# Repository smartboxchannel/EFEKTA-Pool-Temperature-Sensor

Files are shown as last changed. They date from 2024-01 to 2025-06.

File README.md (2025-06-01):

# EFEKTA-Pool-Temperature-Sensor

Проект zigbee датчика температуры для бассейна. Проект разработан на soc сс2530 (радиомодуль E18-MS1PA2-IPX, E18-MS1PA2-PCB, E18-MS1-PCB)

Телеграм чат DIY Devices - https://t.me/diy_devices

Продажа DIY Устройств - https://t.me/diydevmart

Видео инструкция, Ютуб канал SGHome - https://youtu.be/Cri-8IdNB2Q

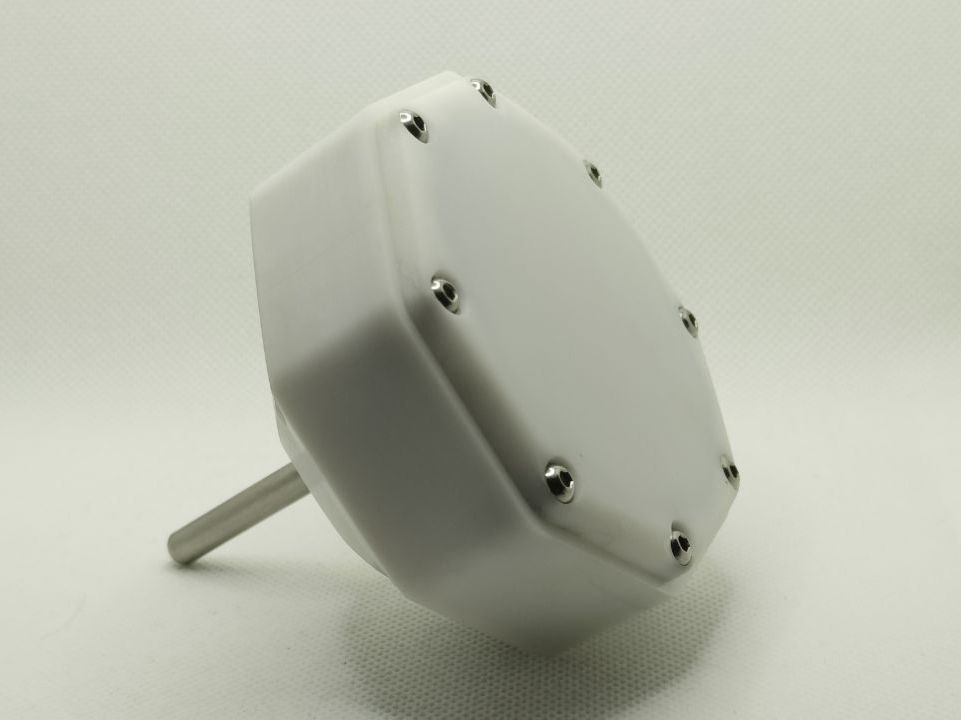
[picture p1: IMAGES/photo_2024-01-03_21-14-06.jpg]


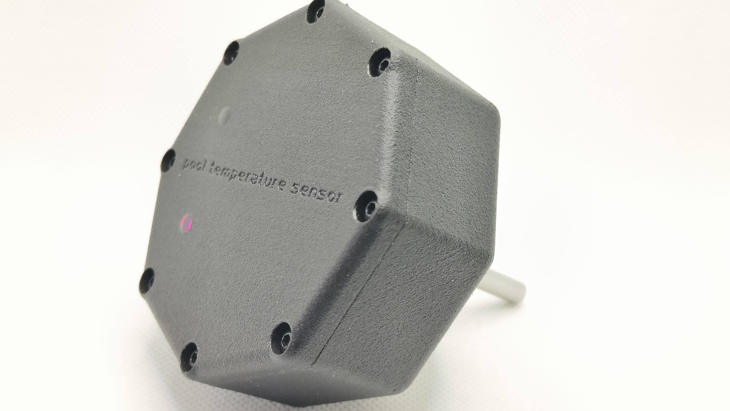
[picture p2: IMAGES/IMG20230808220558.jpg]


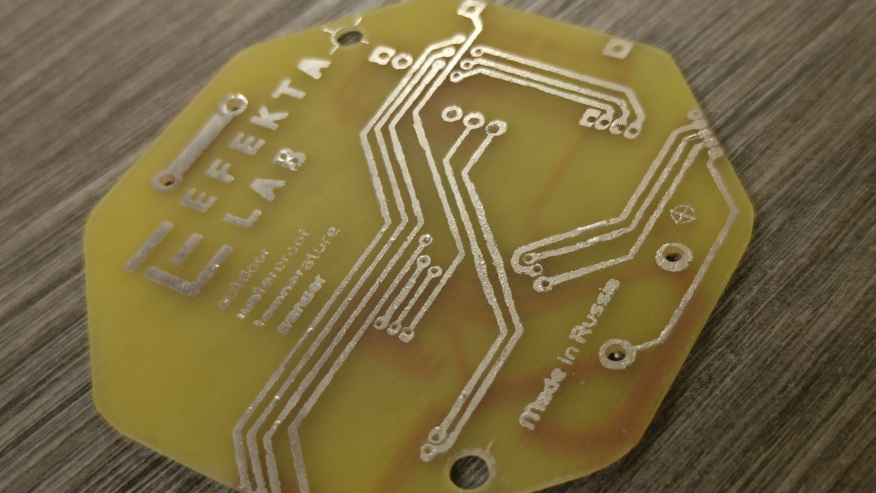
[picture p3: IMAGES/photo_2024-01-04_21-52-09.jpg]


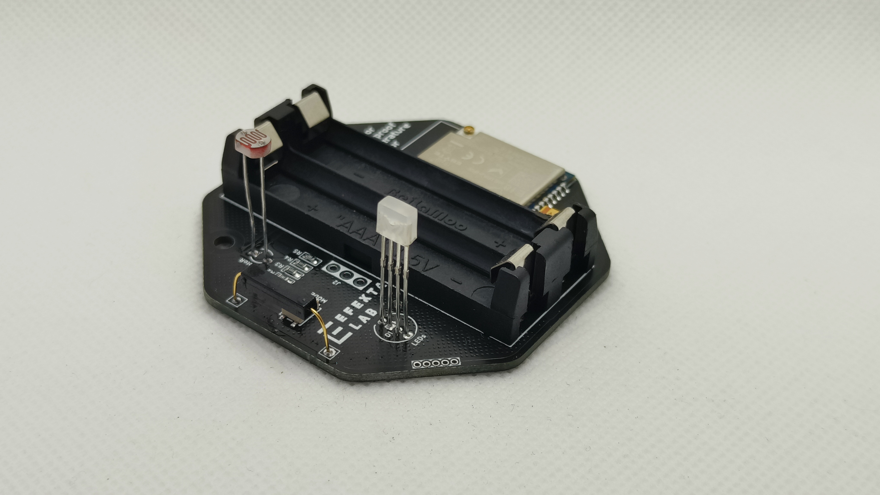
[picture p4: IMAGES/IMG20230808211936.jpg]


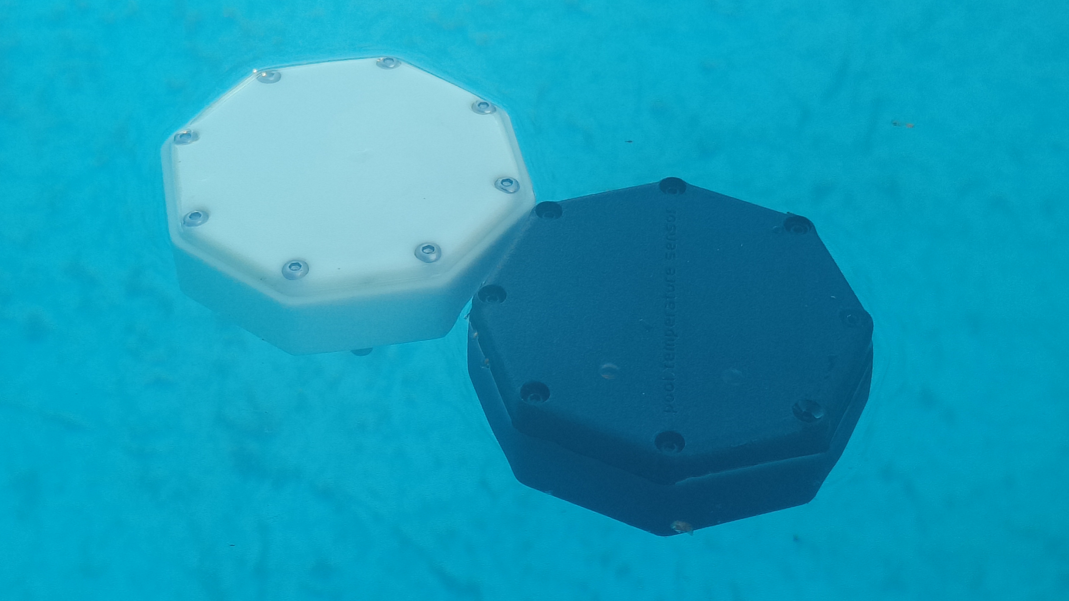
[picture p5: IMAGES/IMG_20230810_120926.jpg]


## Установка среды разработки IAR

https://github.com/sigma7i/zigbee-wiki/wiki/zigbee-firmware-install

https://zigdevwiki.github.io/Begin/IAR_install/

### Программа для разработки печатных плат - DipTrace

https://diptrace.com/rus/download/download-diptrace/

### Корпус спроектирован в SOLIDWORKS

### Прошивка устройства

Вам понадобится программа SmartRF Flash Programmer версии 1. Так же вам понадобится CC Debugger или Smart RF04E(рекомендуется из-за простоты подключения).

#### Процесс прошивки с помощью SmartRF Flash Programmer v1

Подключите 5 контактов на плате на соответствующие подписанные контакты дебагера. Подключаете дебагер в usb порту компьютера, открываете программу SmartRF Flash Programmer v1. Правее поля в пункте Flash Image нажимаете на иконку «обзор» и выбираете файл прошивки скачанный ранее. В пункте Actions выбираете Erase и ниже нажимаете на кнопку Perform actions. После того как вы очистили чип, выбираете Erase and program том же в пункте Actions и снова нажимаете кнопку Perform actions.

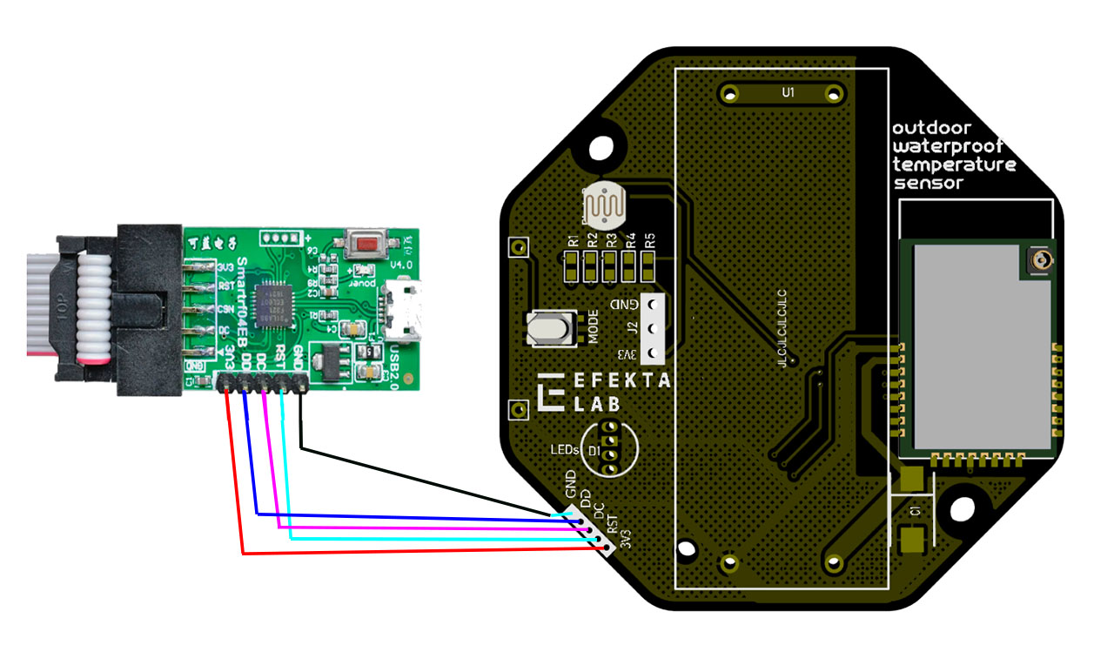
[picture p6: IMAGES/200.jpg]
Flash Programm EFEKTA Pool Temperature Sensor


### Установка внешнего конвертера Z2M

Для добавления внешнего конвертера необходимо выполнить «2 шага». Первый — загрузить сам файл конвертера на ваш сервер, а второй — внести информацию в файл конфигурации о внешнем конвертере в zigbee2mqtt.

To add an external converter you need to perform "2 steps". The first is to upload the converter file itself to your server and the second is to enter information into the configuration about the external converter in zigbee2mqtt. 

#### Добавление файла на сервер.

/UPD
##### Вариант 0.
Если вы используете Home Assistant то загрузить файлы на сервер можно воспользовавшись аддоном File editor (самый простой вариант).

##### 0 option.
If you use Home Assistant to upload files to the server, you can use the File Editor addon (the easiest option).
/

##### Вариант 1.

Для загрузки конвертера для устройсва на сервер УД есть несколько вариантов. Первое это загрузка через ftp клиент. Это может быть любой клиент, например filezilla.

Для подключения к серверу необходимо ввести ip адрес, логин и пароль в соответствуюшие поля в программе и нажать на кнопку - "быстрое подключение"

There are several options for uploading a device converter to the server. The first is uploading via an ftp client. This can be any client, for example filezilla.

To connect to the server, you must enter the IP address, login and password in the appropriate fields of the program and click the “quick connection” button.

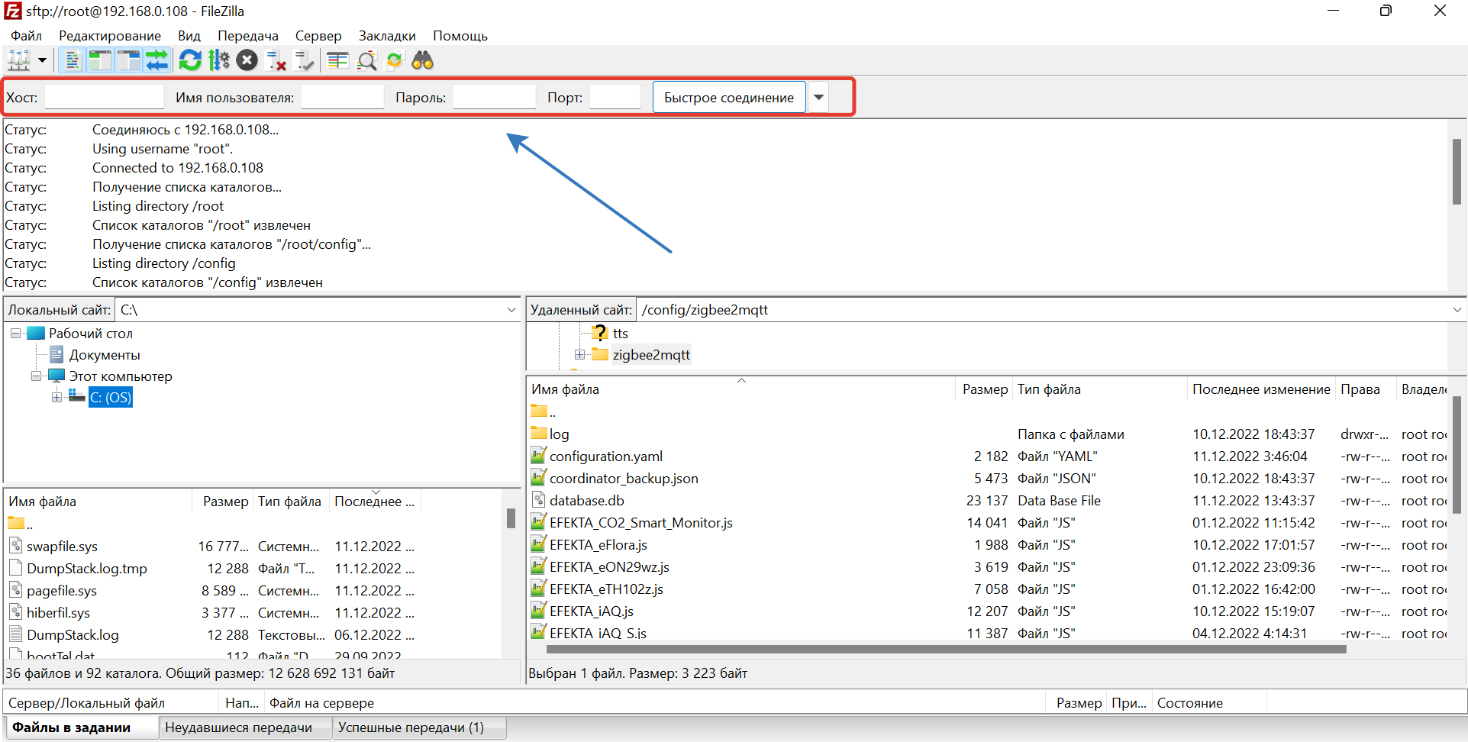
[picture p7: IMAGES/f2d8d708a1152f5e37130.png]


Если вы не используете HassOs то путь к нужной папке будет /opt/zigbee2mqtt/data, если вы используете HassOs то путь к нужной папке будет /config/zigbee2mqtt

Перейдя в нужную папку просто перетащите туда конвертер из левого окна программы в правое.

If you are not using HassOs, then the path to the desired folder will be /opt/zigbee2mqtt/data, if you are using HassOs, then the path to the desired folder will be /config/zigbee2mqtt

Having gone to the desired folder, simply drag the converter there from the left program window to the right one.

##### option 2

Если вы используете Home Assistant то вы можете установить плагин Самба, тогда у вас появится сетевая папка в которую вы можете просто перетащить нужный файл через стандартный проводник в Windows. Инструкция по установке Самба находится здесь http://psenyukov.ru/%D0%B4%D0%B5%D0%BB%D0%B0%D0%B5%D0%BC-%D1%81%D0%B5%D1%82%D0%B5%D0%B2%D1%8B%D0%B5-%D0%BF%D0%B0%D0%BF%D0%BA%D0%B8-%D0%BD%D0%B0-%D1%81%D0%B5%D1%80%D0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.

If you use Home Assistant, then you can install the Samba plugin, then you will have a network folder created in you can simply move the desired file through the standard Windows Explorer. Instructions for installing Samba are here http://psenyukov.ru/%D0%B4%D0%B5%D0%BB%D0%B0%D0%B5%D0%BC-%D1%81%D0%B5%D1%82%D0%B5%D0%B2%D1%8B%D0%B5-%D0%BF%D0%B0%D0%BF%D0%BA%D0%B8-%D0%BD%D0%B0-%D1%81%D0%B5%D1%80%D0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.

#### Добавление записи о внешнем конвертере.

После загрузки файла (это самая трудная часть обычно :)), нужно прописать данные о внешнем конвертере в конфигурацию zigbee2mqtt. Для этого вам нужно перейти в вэбинтерфейс zigbee2mqtt и перейти в раздел - 'настройки".

далее найти подраздел - внешние конвертеры и перейти в него.

After downloading the file (this is usually the hardest part :)), you need to register the data in the external converter in the zigbee2mqtt configuration. To do this, you need to go to the zigbee2mqtt interface and go to the “Settings” section.

Next, find the section - External converters and go to it.

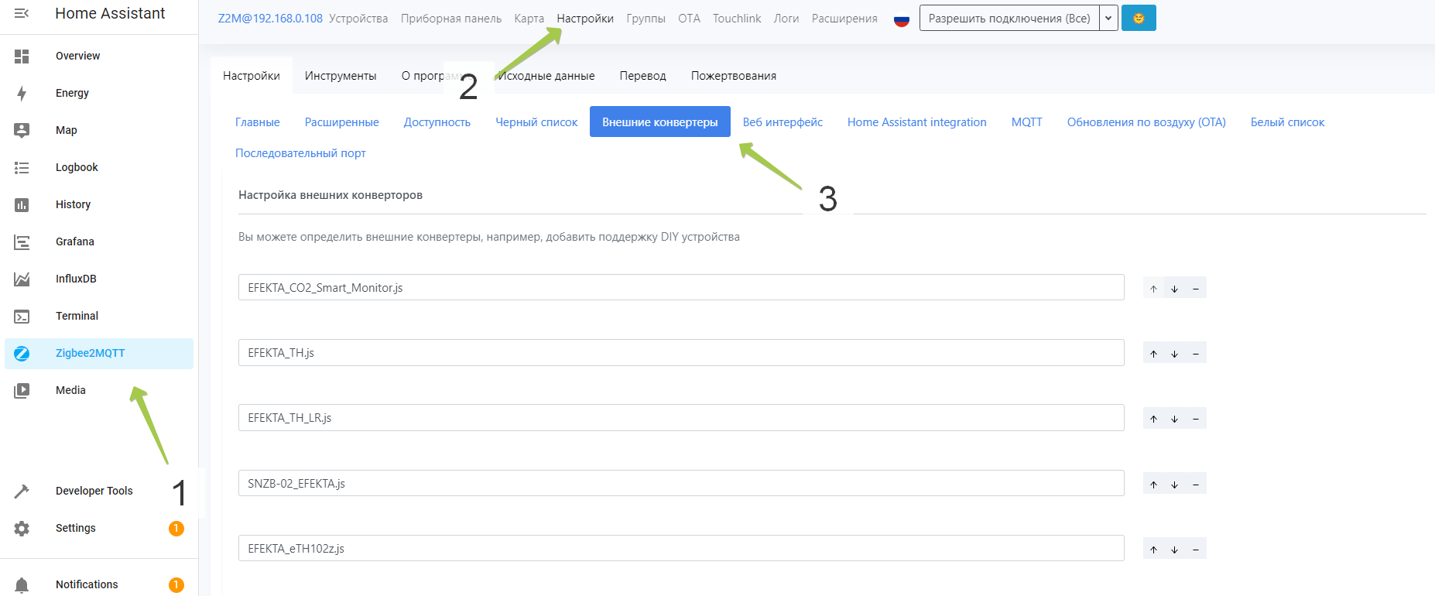
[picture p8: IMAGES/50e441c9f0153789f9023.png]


Далеее нужно спустится вниз страницы и нажать на кнопку "+", появися новое окно для ввода информации, туда нужно добавить название вашего внешнего конвертера с расширением. например Pool_Temperature_smart_sensor.js. После этого нажать на кнопку 'Submit" и далее на кнопку - "Перезагрузить" вверху страницы.

Next, you need to scroll down the page and click the “+” button, a new window will appear for entering information, where you need to add the name of your external converter with extensions. for example Pool_Temperature_smart_sensor.js. After that, click on the “Submit” button and then on the “Reload” button at the top of the page.

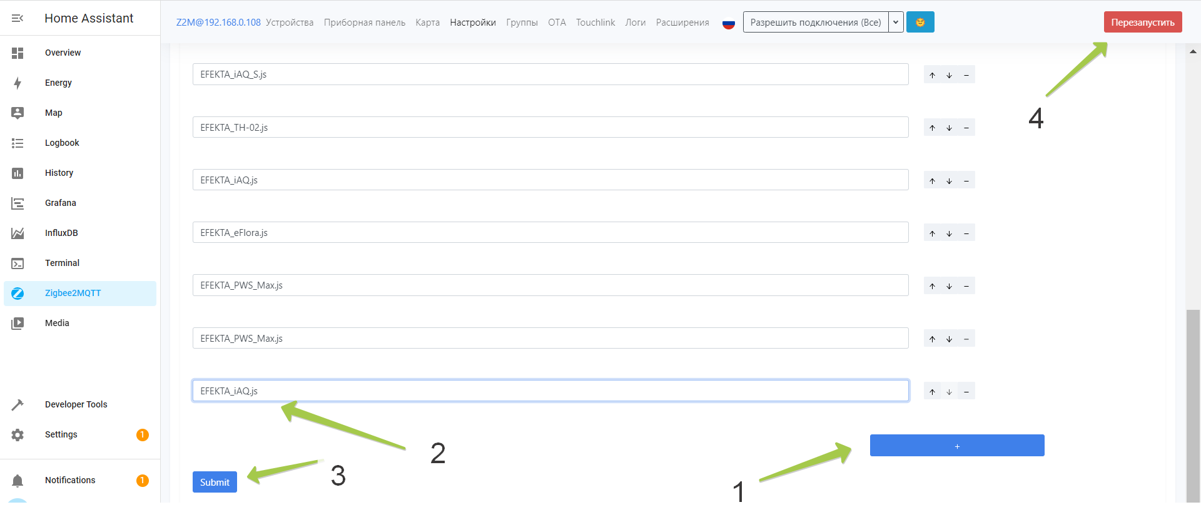
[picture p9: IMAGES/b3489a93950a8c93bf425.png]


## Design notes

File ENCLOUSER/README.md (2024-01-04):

#### Медная гайка M3 (OD 4.5mm), Length 5mm 

https://aliexpress.ru/item/1005004873154281.html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

#### Винт М3х10 ISO 7380 под шестигранник, нержавейка 

https://market.yandex.ru/product--vint-m3kh10-iso-7380-a2-pod-shestigrannik-10-shtuk-nerzhaveika-m3-7380-1-din-7985-s-polukrugloi-golovkoi-gost/1776518320?sku=101849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

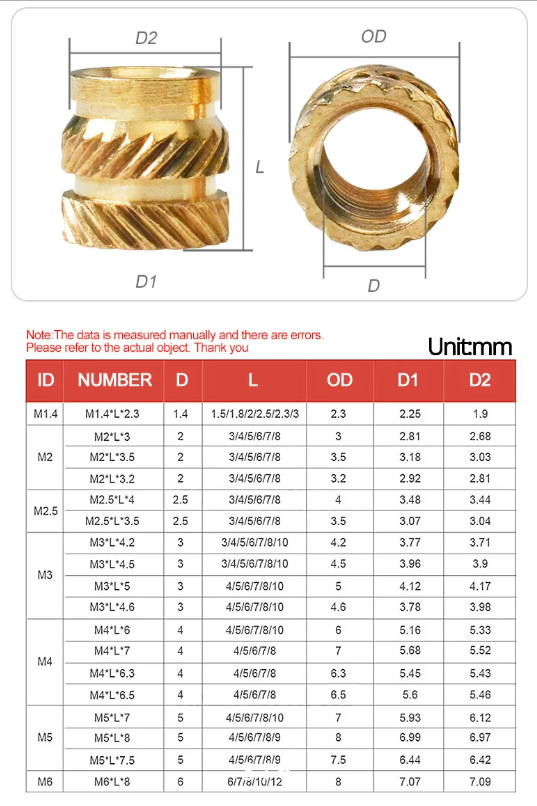
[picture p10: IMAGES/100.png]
Медная гайка M3 (OD 4.5mm), Length 5mm EFEKTA Pool Temperature Sensor


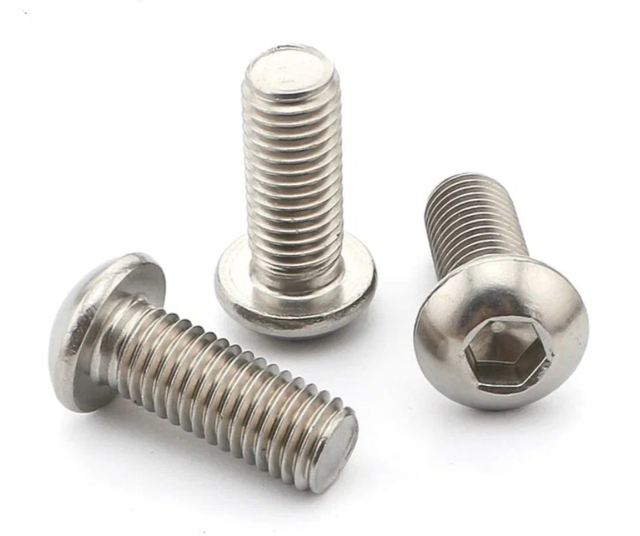
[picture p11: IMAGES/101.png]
Винт М3х10 ISO 7380 под шестигранник, нержавейка EFEKTA Pool Temperature Sensor


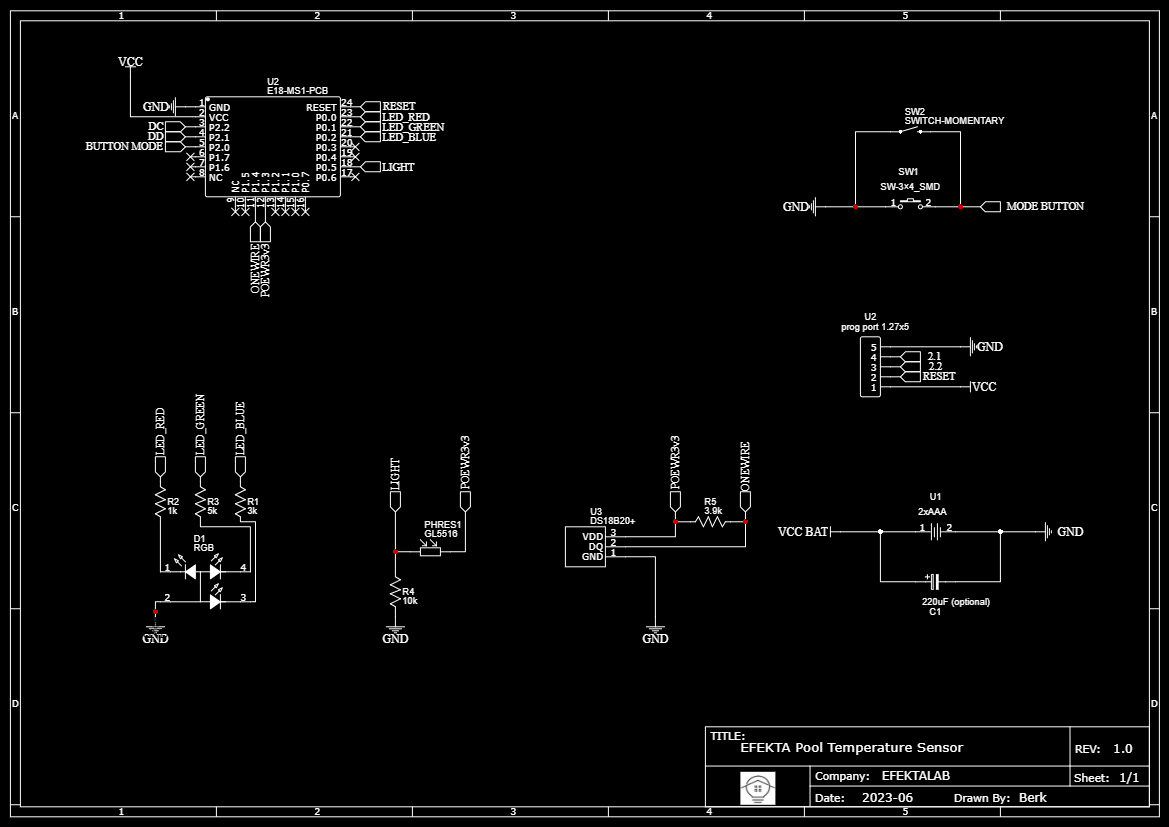
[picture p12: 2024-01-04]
SCHEMATIC/Schematic.png

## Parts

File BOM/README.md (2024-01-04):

220uF (optional)	https://aliexpress.ru/order-list/5287508838095037

SW-3×4_SMD	https://aliexpress.ru/item/32696281655.html

RGB LED	https://aliexpress.ru/item/1005004567358995.html?sku_id=12000029654169032

GL5528	https://aliexpress.ru/item/32623615207.html

3k	https://aliexpress.ru/item/1005001793547200.html

1k	https://aliexpress.ru/item/1005001907419076.html

5k	https://aliexpress.ru/item/32858644837.html

10k	https://aliexpress.ru/item/32951328488.html

3.9k	https://aliexpress.ru/item/1005001907419076.html

REED SWITCH-MOMENTARY	https://aliexpress.ru/item/1005005564419910.html

2xAAA Holder	https://aliexpress.ru/item/1005005510031586.html

E18-MS1PA2-IPX	https://aliexpress.ru/item/4000818220197.html

DS18B20	https://aliexpress.ru/item/1005005221586555.html

5dBi IPX IPEX	https://aliexpress.ru/item/32954206141.html



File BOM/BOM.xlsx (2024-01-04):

ID | Name | Designator | Footprint | Quantity | Link
1 | 220uF (optional) | C1 | CASE-C | 1 | https://aliexpress.ru/order-list/5287508838095037
2 | SW-3×4_SMD | SW1 | KEY-SMD_3x4 | 1 | https://aliexpress.ru/item/32696281655.html
3 | RGB LED | D1 | LED(TRI)-5R | 1 | https://aliexpress.ru/item/1005004567358995.html?sku_id=12000029654169032
4 | GL5528 | PHRES1 | LDR 5mm | 1 | https://aliexpress.ru/item/32623615207.html
5 | 3k | R1 | R0603 | 1 | https://aliexpress.ru/item/1005001793547200.html
6 | 1k | R2 | R0603 | 1 | https://aliexpress.ru/item/1005001907419076.html
7 | 5k | R3 | R0603 | 1 | https://aliexpress.ru/item/32858644837.html
8 | 10k | R4 | R0603 | 1 | https://aliexpress.ru/item/32951328488.html
9 | 3.9k | R5 | R0603 | 1 | https://aliexpress.ru/item/1005001907419076.html
10 | REED SWITCH-MOMENTARY | SW1 | REED_SWITCH_PLASTIC | 1 | https://aliexpress.ru/item/1005005564419910.html
11 | 2xAAA Holder | U1 | ААА Holder | 1 | https://aliexpress.ru/item/1005005510031586.html
13 | E18-MS1PA2-IPX | U2 | SMD_E18-MS1PA2-IPX | 1 | https://aliexpress.ru/item/4000818220197.html
14 | DS18B20 | U3 | TO-92-3 | 1 | https://aliexpress.ru/item/1005005221586555.html
15 | 5dBi IPX IPEX |  |  |  | https://aliexpress.ru/item/32954206141.html

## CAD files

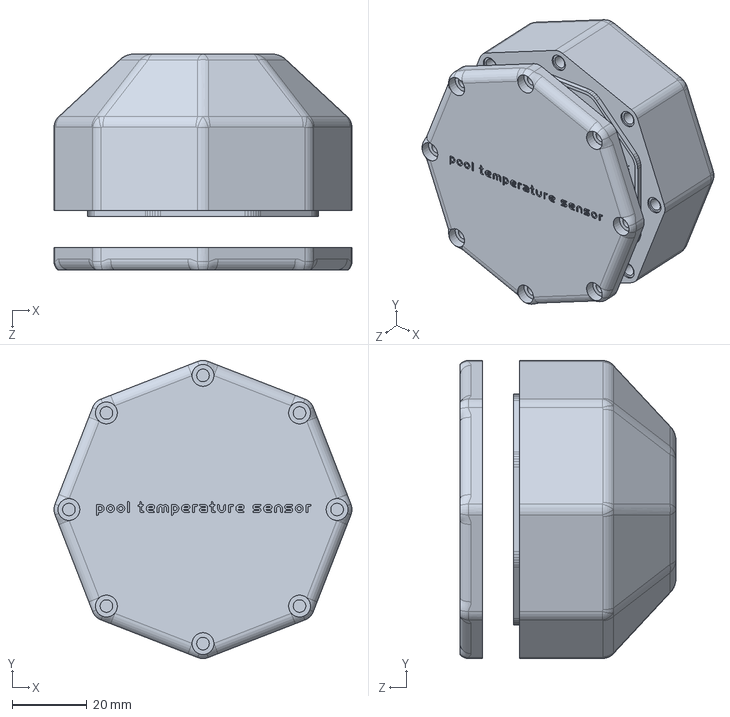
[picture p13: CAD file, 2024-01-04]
ENCLOUSER/SOLIDWORKS/pt.SLDPRT
80.0 x 80.0 x 58.0 mm

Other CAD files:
ENCLOUSER/pt.STL

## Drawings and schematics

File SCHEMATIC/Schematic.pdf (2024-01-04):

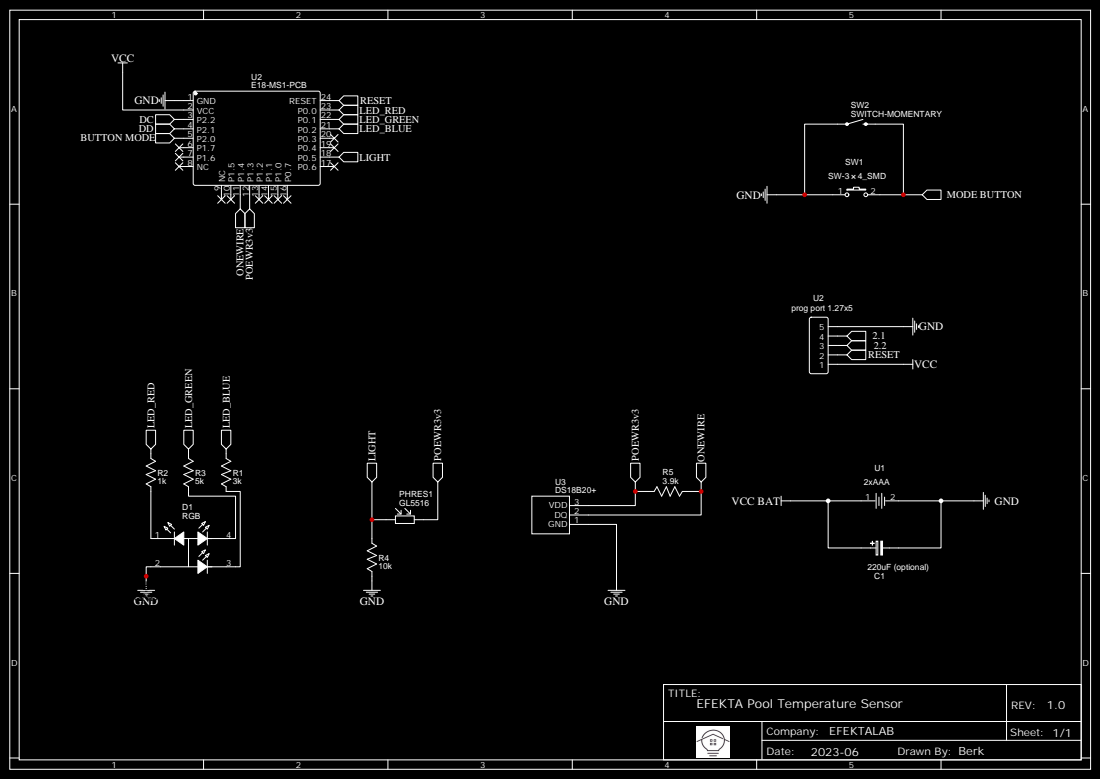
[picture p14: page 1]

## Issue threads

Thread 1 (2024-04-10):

Подключение DS18B20

booroondook-eng, 2024-04-10:
Я подключил ножку VCC датчика DS18B20 так, как указано на вашей схеме - то есть к пину P1.3 (он у вас обозначен как POEWR3V3). И прибор стал выдавать постоянно температуру +25 градусов по Цельсию без каких-либо изменений.
Тогда я переключил VCC датчика на плюс питания (3V3), и датчик нормально заработал - то есть, показания температуры стали меняться во времени.
Скажите, в чём я неправ?

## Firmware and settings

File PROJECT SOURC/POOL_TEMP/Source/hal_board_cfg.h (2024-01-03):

#ifndef HAL_BOARD_CFG_H
#define HAL_BOARD_CFG_H


/* ------------------------------------------------------------------------------------------------
 *                                           Includes
 * ------------------------------------------------------------------------------------------------
 */

#include "hal_mcu.h"
#include "hal_defs.h"
#include "hal_types.h"


/* ------------------------------------------------------------------------------------------------
 *                                       CC2590/CC2591 support
 *
 *                        Define HAL_PA_LNA_CC2590 if CC2530+CC2590EM is used
 *                        Define HAL_PA_LNA if CC2530+CC2591EM is used
 *                        Note that only one of them can be defined
 * ------------------------------------------------------------------------------------------------
 */



/* ------------------------------------------------------------------------------------------------
 *                                          Clock Speed
 * ------------------------------------------------------------------------------------------------
 */

#define HAL_CPU_CLOCK_MHZ     32

/* 32 kHz clock source select in CLKCONCMD */
#if !defined (OSC32K_CRYSTAL_INSTALLED) || (defined (OSC32K_CRYSTAL_INSTALLED) && (OSC32K_CRYSTAL_INSTALLED == TRUE))
#define OSC_32KHZ  0x00 /* external 32 KHz xosc */
#else
#define OSC_32KHZ  0x80 /* internal 32 KHz rcosc */
#endif

#define HAL_CLOCK_STABLE() 

/* ------------------------------------------------------------------------------------------------
 *                                         Key Release detect support
 * ------------------------------------------------------------------------------------------------
 */
#define HAL_KEY_CODE_NOKEY 0xff


/* ------------------------------------------------------------------------------------------------
 *                                       LED Configuration
 * ------------------------------------------------------------------------------------------------
 */

// TODO: review all HAL_BOARD_CC2530EB_REV17 and replace with HAL_BOARD_CC2530RC
//       if applicable.
#define HAL_NUM_LEDS            0

#define HAL_LED_BLINK_DELAY()   st( { volatile uint32 i; for (i=0; i<0x5800; i++) { }; } )
#define ACTIVE_LOW        !
#define ACTIVE_HIGH       !!    /* double negation forces result to be '1' */

/* ------------------------------------------------------------------------------------------------
 *                         OSAL NV implemented by internal flash pages.
 * ------------------------------------------------------------------------------------------------
 */

// Flash is partitioned into 8 banks of 32 KB or 16 pages.
#define HAL_FLASH_PAGE_PER_BANK    16
// Flash is constructed of 128 pages of 2 KB.
#define HAL_FLASH_PAGE_SIZE        2048
#define HAL_FLASH_WORD_SIZE        4

// CODE banks get mapped into the XDATA range 8000-FFFF.
#define HAL_FLASH_PAGE_MAP         0x8000

// The last 16 bytes of the last available page are reserved for flash lock bits.
// NV page definitions must coincide with segment declaration in project *.xcl file.
#if defined NON_BANKED
#define HAL_FLASH_LOCK_BITS        16
#define HAL_NV_PAGE_END            30
#define HAL_NV_PAGE_CNT            2
#else
#define HAL_FLASH_LOCK_BITS        16
#define HAL_NV_PAGE_END            126
#define HAL_NV_PAGE_CNT            6
#endif

// Re-defining Z_EXTADDR_LEN here so as not to include a Z-Stack .h file.
#define HAL_FLASH_IEEE_SIZE        8
#define HAL_FLASH_IEEE_PAGE       (HAL_NV_PAGE_END+1)
#define HAL_FLASH_IEEE_OSET       (HAL_FLASH_PAGE_SIZE - HAL_FLASH_LOCK_BITS - HAL_FLASH_IEEE_SIZE)
#define HAL_INFOP_IEEE_OSET        0xC

#define HAL_FLASH_DEV_PRIVATE_KEY_OSET     0x7D2
#define HAL_FLASH_CA_PUBLIC_KEY_OSET       0x7BC
#define HAL_FLASH_IMPLICIT_CERT_OSET       0x78C

#define HAL_NV_PAGE_BEG           (HAL_NV_PAGE_END-HAL_NV_PAGE_CNT+1)
// Used by DMA macros to shift 1 to create a mask for DMA registers.
#define HAL_NV_DMA_CH              0
#define HAL_DMA_CH_RX              3
#define HAL_DMA_CH_TX              4

#define HAL_NV_DMA_GET_DESC()      HAL_DMA_GET_DESC0()
#define HAL_NV_DMA_SET_ADDR(a)     HAL_DMA_SET_ADDR_DESC0((a))

/* ------------------------------------------------------------------------------------------------
 *  Serial Boot Loader: reserving the first 4 pages of flash and other memory in cc2530-sb.xcl.
 * ------------------------------------------------------------------------------------------------
 */

#define HAL_SB_IMG_ADDR       0x2000
#define HAL_SB_CRC_ADDR       0x2090
// Size of internal flash less 4 pages for boot loader, 6 pages for NV, & 1 page for lock bits.
#define HAL_SB_IMG_SIZE      (0x40000 - 0x2000 - 0x3000 - 0x0800)
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

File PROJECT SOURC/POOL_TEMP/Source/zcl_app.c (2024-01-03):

#include "AF.h"
#include "OSAL.h"
#include "OSAL_Clock.h"
#include "OSAL_PwrMgr.h"
#include "ZComDef.h"
#include "ZDApp.h"
#include "ZDNwkMgr.h"
#include "ZDObject.h"
#include "math.h"
#include "nwk_util.h"
#include "zcl.h"
#include "zcl_app.h"
#include "zcl_diagnostic.h"
#include "zcl_general.h"
#include "zcl_ms.h"
#include "bdb.h"
#include "bdb_interface.h"
#include "gp_interface.h"
#include "OnBoard.h"
#include "math.h"
#include "stdio.h"
#include "stdlib.h"

#include "hal_adc.h"
#include "hal_drivers.h"
#include "hal_key.h"
#include "hal_led.h"
#include "battery.h"
#include "commissioning.h"
#include "factory_reset.h"
#include "utils.h"
#include "ds18b20.h"

#define HAL_KEY_CODE_RELEASE_KEY HAL_KEY_CODE_NOKEY
#define myround(x) ((int)((x)+0.5))

#define POWER_ON_SENSORS()                                                                                                                 \
    do {                                                                                                                                   \
        HAL_TURN_ON_LED4();                                                                                                                \
        IO_PUD_PORT(DS18B20_PORT, IO_PUP);                                                                                                 \
    } while (0)
#define POWER_OFF_SENSORS()                                                                                                                \
    do {                                                                                                                                   \
        HAL_TURN_OFF_LED4();                                                                                                               \
        IO_PUD_PORT(DS18B20_PORT, IO_PDN);                                                                                                 \
    } while (0)

extern bool requestNewTrustCenterLinkKey;
byte zclApp_TaskID;

static bool initOut = false;
static bool pushBut = false;
static uint8 currentSensorsReadingPhase = 0;
static uint8 currentSensorsSendingPhase = 0;
static uint8 currentSensorsSendingPeriodicPhase = 0;
static uint8 currentSensorsSendingMRPhase = 0;
static int16 sendInitReportCount = 0;
static int16 temp_old = 0;
static int16 temp_tr = 15;
static uint16 lumi_old = 0;
static uint16 lumi_tr = 50;

uint8 SeqNum = 0;
afAddrType_t inderect_DstAddr = {.addrMode = (afAddrMode_t)AddrNotPresent, .endPoint = 0, .addr.shortAddr = 0};

static void zclApp_BasicResetCB(void);
static void zclApp_RestoreAttributesFromNV(void);
static void zclApp_SaveAttributesToNV(void);
static ZStatus_t zclApp_ReadWriteAuthCB(afAddrType_t *srcAddr, zclAttrRec_t *pAttr, uint8 oper);
static void zclApp_HandleKeys(byte shift, byte keys);
static void zclApp_Report(void);
static void zclApp_ReportPeriodic(void);
static void zclApp_ReportBatt(void);
static void zclBattery_Report(void);
static void zclApp_ReadSensors(void);
static void zclApp_SendSensors(void);
static void zclApp_SendPeriodicSensors(void);
static void zclApp_SendMandatoryReport(void);
static void zclConfigReport(void);
static void zclApp_ReadDS18B20(void);
static void zclApp_ReadLum(void);
static void zclApp_SendTemp(void);
static void zclApp_SendLum(void);
static void zclApp_ReportTemp(void);
static void zclApp_ReportLumosity(void);
static void zclApp_LedOn(void);
static void zclApp_LedOff(void);

static zclGeneral_AppCallbacks_t zclApp_CmdCallbacks = {
    zclApp_BasicResetCB, // Basic Cluster Reset command
    NULL, // Identify Trigger Effect command
    NULL, // On/Off cluster commands
    NULL, // On/Off cluster enhanced command Off with Effect
    NULL, // On/Off cluster enhanced command On with Recall Global Scene
    NULL, // On/Off cluster enhanced command On with Timed Off
    NULL, // RSSI Location command
    NULL  // RSSI Location Response command
};

void zclApp_Init(byte task_id) {
    zclApp_RestoreAttributesFromNV();
  
    HAL_TURN_ON_LED1();
    user_delay_ms(1500);
    HAL_TURN_OFF_LED1();
    IO_IMODE_PORT_PIN(LUMOISITY_PORT, LUMOISITY_PIN, IO_TRI);
    POWER_OFF_SENSORS();
    
    requestNewTrustCenterLinkKey = FALSE;
    zclApp_TaskID = task_id;
    zclGeneral_RegisterCmdCallbacks(1, &zclApp_CmdCallbacks);
    zcl_registerAttrList(zclApp_FirstEP.EndPoint, zclApp_AttrsFirstEPCount, zclApp_AttrsFirstEP);
    bdb_RegisterSimpleDescriptor(&zclApp_FirstEP);
    zcl_registerReadWriteCB(zclApp_FirstEP.EndPoint, NULL, zclApp_ReadWriteAuthCB);
    zcl_registerForMsg(zclApp_TaskID);
    RegisterForKeys(zclApp_TaskID);
    
    zclApp_ReadSensors();
    osal_start_timerEx(zclApp_TaskID, APP_REPORT_EVT, 15000);
    osal_start_reload_timer(zclApp_TaskID, APP_REPORT_PER_EVT, 1800101);
    osal_start_reload_timer(zclApp_TaskID, APP_REPORT_BATT_EVT, 10600202);
    osal_start_timerEx(zclApp_TaskID, APP_LED_PERIOD_EVT, zclApp_Config.LedFreq*1000);
}
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

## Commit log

2024-01-03 With built-in device image.
    With built-in device image.
2024-04-01 With built-in device image.
